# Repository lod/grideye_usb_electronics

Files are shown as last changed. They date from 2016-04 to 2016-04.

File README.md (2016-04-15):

GridEye USB Board
=================

This board is designed to allow a USD host to connect to a Panasonic GridEye sensor.

The files were generated by and can be opened by KiCad.

This is version 1 of the board. The PCBs have been sent off to be fabricated, grideye_usb_two_sided_gerbers.zip contains a set of gerbers suitable for use by OSHPark.

The design **probably** does not work. The parts have never been placed on the board, the board has never been powered up, no firmware has been written... the availability of this design should be considered an academic curiosity, not something to use.

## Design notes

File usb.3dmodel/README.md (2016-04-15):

From https://github.com/kylemanna/kicad-library

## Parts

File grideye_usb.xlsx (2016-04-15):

 |  |  |  |  |  |  | Board Qty: | 1
 |  |  |  |  |  |  | Total Cost: | $2.60 |  |  |  | $2.57 |  |  |  |  |  | $2.68 |  |  |  |  |  | $4.54
 |  |  |  |  |  |  | Unit Cost: | $2.60
Global Part Info |  |  |  |  |  |  |  |  | Digi-Key |  |  |  |  |  | Mouser |  |  |  |  |  | Element14 (AUD)
Refs | Value | Desc | Footprint | Manf | Manf# | Qty | Unit$ | Ext$ | Avail | Purch | Unit$ | Ext$ | Cat# | Doc | Avail | Purch | Unit$ | Ext$ | Cat# | Doc | Avail | Purch | Unit$ | Ext$ | Cat# | Doc
C10 | 1uF |  | Capacitors_SMD:C_0603 |  |  | 1 | $0.00 | $0.00
U1 | MIC5205-x.x |  | TO_SOT_Packages_SMD:SOT-23-5 |  | MIC5205-3.3YM5 TR | 1 | $0.40 | $0.40 | 33014 |  | $0.40 | $0.40 | 576-1259-1-ND | Link (http://www.digikey.com/product-detail/en/microchip-technology/MIC5205-3.3YM5-TR/576-1259-1-ND/771886) | 6572 |  | $0.47 | $0.47 | 998-MIC5205-3.3YM5TR | Link (http://www.mouser.com/Search/Refine.aspx?Keyword=MIC5205-3.3YM5%20TR%20) | 399 |  | $0.84 | $0.84 | 2510222 | Link (http://www.newark.com/webapp/wcs/stores/servlet/Search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)
C11 | 1.5uF |  | Capacitors_SMD:C_0603 |  |  | 1 | $0.00 | $0.00
R1 | DNF |  | Resistors_SMD:R_0603 |  |  | 1 | $0.00 | $0.00
R8 | 20R |  | Resistors_SMD:R_0603 |  |  | 1 | $0.00 | $0.00
C1 | 2.2uF |  | SMD_Packages:SMD-1210_Pol |  | TAJB225K035RNJ | 1 | $0.19 | $0.19 |  |  |  |  |  |  |  |  |  |  |  |  | 1563 |  | 0.186 | 0.186 | 1432360
R2 | 1k5 |  | Resistors_SMD:R_0603 |  |  | 1 | $0.00 | $0.00
C2 | 470pF |  | Capacitors_SMD:C_0603 |  |  | 1 | $0.00 | $0.00
C7,C9 | 10uF |  | Capacitors_SMD:C_0603 |  |  | 2 | $0.00 | $0.00
R3,R4 | 68R |  | Resistors_SMD:R_0603 |  |  | 2 | $0.00 | $0.00
R5-R7 | 10k |  | Resistors_SMD:R_0603 |  |  | 3 | $0.00 | $0.00
D1,D2 | 3V6 |  | Diodes_SMD:SOD-323 |  | Dz2J036M0L | 2 | $0.10 | $0.20 | 1594 |  | $0.10 | $0.20 | DZ2J036M0LCT-ND | Link (http://www.digikey.com/product-detail/en/panasonic-electronic-components/DZ2J036M0L/DZ2J036M0LCT-ND/2704456) | 13830 |  | $0.20 | $0.39 | 667-DZ2J036M0L | Link (http://www.mouser.com/Search/Refine.aspx?Keyword=Dz2J036M0L%20) | 1079 |  | 0.288 | 0.288 | 2285294
C8 | 0.1uF |  | Capacitors_SMD:C_0603 |  |  | 1 | $0.00 | $0.00
P2 | USB_B |  | Connect:USB_Micro-B |  | 10118194-0001LF | 1 | $0.40 | $0.40 | 115384 |  | $0.46 | $0.46 | 609-4618-1-ND | Link (http://www.digikey.com/product-detail/en/amphenol-fci/10118194-0001LF/609-4618-1-ND/2785382) | 18246 |  | $0.40 | $0.40 | 649-10118194-0001LF | Link (http://www.mouser.com/Search/Refine.aspx?Keyword=10118194-0001LF%20) | 1133 |  | 0.517 | 0.517 | 2506570
IC1 | ATTINY45-S |  | Housings_SOIC:SOIC-8_3.9x4.9mm_Pitch1.27mm |  | ATTINY45-20SU | 1 | $1.41 | $1.41 | 26887 |  | $1.51 | $1.51 | ATTINY45-20SU-ND | Link (http://www.digikey.com/product-detail/en/atmel/ATTINY45-20SU/ATTINY45-20SU-ND/735466) | 1103 |  | $1.41 | $1.41 | 556-ATTINY45-20SUR | Link (http://www.mouser.com/ProductDetail/Atmel/ATTINY45-20SUR/) | 2605 |  | 2.7 | $2.70 | 1288353
U2 | GridEye |  | Grideye:AMG8851 |  |  | 1 | $0.00 | $0.00
P1 | TC2030-IDC |  |  |  |  | 1 | $0.00 | $0.00
C3-C6 | DNF |  | Capacitors_SMD:C_0603 |  |  | 4 | $0.00 | $0.00

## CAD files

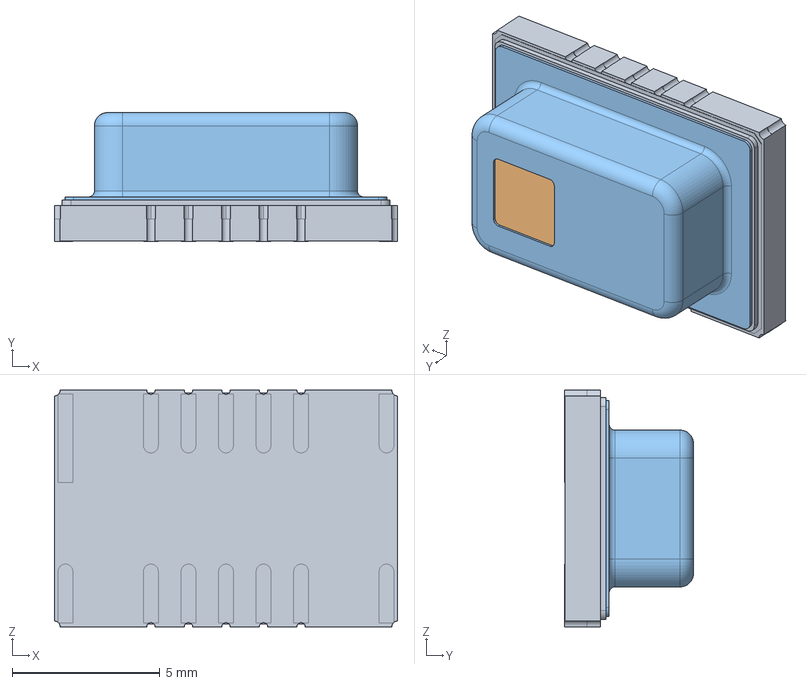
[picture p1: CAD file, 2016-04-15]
grideye.3dmodel/coloured.fcstd
11.6 x 4.36 x 8.00 mm
base
window

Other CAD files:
grideye.3dmodel/Grid-EYE_3D.STEP

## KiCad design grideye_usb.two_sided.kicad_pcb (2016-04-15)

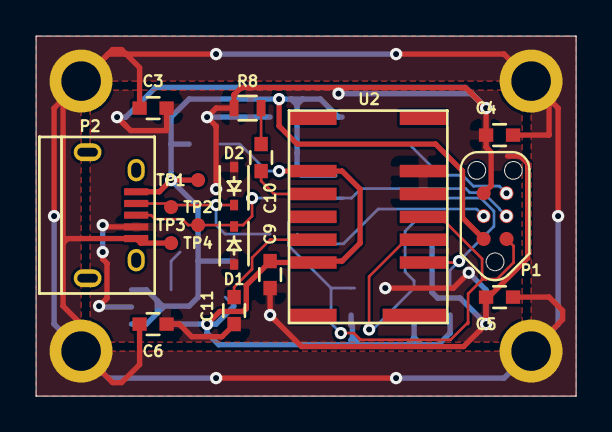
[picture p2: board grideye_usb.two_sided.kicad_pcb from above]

Board: 2 copper layers, 30.0 x 20.0 mm, 31 parts (0 on the bottom side), 16 nets.

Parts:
C1: 2.2uF; SMD-1210_Pol
C2: 470pF; C_0603
C3, C4, C5, C6: DNF; C_0603
C7, C9: 10uF; C_0603
C8: 0.1uF; C_0603
C10: 1uF; C_0603
C11: 1.5uF; C_0603
D1, D2: 3V6; SOD-323
IC1: ATTINY45-S; SOIC-8_3.9x4.9mm_Pitch1.27mm
P1: TC2030-IDC; TC2030-NL_SMALL
P2: USB_B; USB_Micro-B
R1: DNF; R_0603
R2: 1k5; R_0603
R3, R4: 68R; R_0603
R5, R6, R7: 10k; R_0603
R8: 20R; R_0603
R9: 4k7; R_0603
TP1, TP2, TP3, TP4: Measurement_Point_Round-SMD-Pad_Small
U1: MIC5205-x.x; SOT-23-5
U2: GridEye; AMG8851

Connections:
/INT: IC1.6, P1.1, R7.2, U2.4
/MOSI: IC1.5, P1.4, R3.2
/RST: IC1.1, P1.5, R9.2
/SCK: IC1.7, P1.3, R4.2
/SCL: IC1.3, R6.2, U2.3
/SDA: IC1.2, R5.2, U2.2
/USB_N: D2.1, P2.2, R2.2, R3.1, TP2.1
/USB_P: D1.1, P2.3, R4.1, TP3.1
GND: C1.2, C2.2, C3.2, C4.1, C5.2, C6.1, C7.2, C8.2, C9.2, C11.2, D1.2, D2.2, IC1.4, P1.6, P2.4, R8.2, U1.2, U2.5, U2.6
GNDPWR: C3.1, C4.2, C5.1, C6.2, P2.5, TP4.1
unnamed: C2.1, U1.4
unnamed: C10.1, U2.10
unnamed: C10.2, R8.1
unnamed: C11.1, U2.12
vsens: C1.1, C9.1, R1.1, R5.1, R6.1, R7.1, U1.5, U2.9, U2.13
vusb: C7.1, C8.1, IC1.8, P1.2, P2.1, R1.2, R2.1, R9.1, TP1.1, U1.1, U1.3

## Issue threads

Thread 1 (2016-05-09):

IC1 pad incorrect

lod, 2016-05-09:
Footprint for ATTiny45 is wrong, too narrow

The footprint is the Atmel S8S1 footprint, JEDEC SOIC

I bought WSOIC chips, looks like they match the Atmel 8S2 footprint
